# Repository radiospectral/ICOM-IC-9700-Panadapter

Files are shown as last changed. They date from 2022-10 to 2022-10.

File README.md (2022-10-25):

# ICOM-IC-9700-Panadapter
RF out for ICOM-IC-9700

DISCLAIMER:
We are not responsible for any damage to your radio, and this is at your own risk operation.
If you don't have the basic electronic knowledge, we do not suggest you attempt to build this unit.

SCHEMATICS-ICOM-IC-9700-Panadapter.pdf : Schematic file.

gerber.zip                             : Zip archive, constains gerber files for the PCB manufacturing.
                                         You can use jlcpcb.com to order ready to use PCBs.

pcb-manufacture.png                    : PCB manufacturing settings for jlcpcb.com

BOM-ICOM-IC-9700-Panadapter.pdf        : Bill of materials.

fixture-9700.step                      : Fixture step file.  You may also print the part with 3D printer.

IMPORTANT:
The thickness of the PCB should be 1mm, and FR4 should be used as a material.

We encourage you to share this project with other ham radio operators to help them monitor the spectrum of amateur bands
with their SDR receivers. 

We hope our contribution helps the ham radio community to build low cost and effective pan adapters for their rigs.

www.radiospectral.com

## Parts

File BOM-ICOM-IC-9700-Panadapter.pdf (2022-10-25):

Designator | Value | Description | Digi-Key_Purchase_URL | Digi-Key_Part_Number | Quantity
12RIF, 12RIFIN, RF_OUT, URRF, URRFIN, VRRF, VRRFIN | UF.L | Conn Coaxial PL 50Ohm Solder ST SMD Gold Over Nickel | https://www.digikey.com/product-detail/en/te-connectivity-amp-connectors/1909763-1/A118077DKR-ND/4914093 | A118077DKR-ND | 7
C1, C4 | 10uF | Cap Ceramic 10uF 25V X5R 10% SMD 0805 85Â°C Embossed T/R | https://www.digikey.com.tr/product-detail/en/samsung-electro-mechanics/CL21A106KAYNNNE/1276-2891-1-ND/3890977 | 1276-2891-6-ND | 2
C2, C5 | 1uF 16V | Eia Case Size: 0805, Voltage: 50, Cap Value: 1000000, Tol: +/-10%, Thickness: 1.25 Â± 0.20 | https://www.digikey.com/product-detail/en/kemet/C0805C105Z4VACTU/399-8011-6-ND/3472542 | 399-8011-6-ND | 2
C3, C6, C7, C8, C9, CF, CFA, CFB, CFC | 100nF 50V | CAP CER 1000PF 50V C0G/NP0 0805, CAP CER 100nF 50V C0G/NP0 0805, Eia Case Size: 0805, Voltage: 50, Cap Value: 100000, Tol: +/-10%, Thickness: 1.25 Â± 0.20 | https://www.digikey.com/product-detail/en/tdk-corporation/CGA4J2X8R1H104K125AA/445-5909-6-ND/2444516 | 445-5909-6-ND | 9
CINA, CINB, CINC | 100nF | Eia Case Size: 0805, Voltage: 50, Cap Value: 100000, Tol: +/-10%, Thickness: 1.25 Â± 0.20 | https://www.digikey.com/product-detail/en/samsung-electro-mechanics/CL10B104KA8NNNC/1276-1006-1-ND/3889092 | 1276-1006-1-ND | 3
COUT | 10nF | Eia Case Size: 0805, Voltage: 50, Cap Value: 10000, Tol: +/-10%, Thickness: 1.25 Â± 0.20 | https://www.digikey.com/product-detail/en/samsung-electro-mechanics/CL21C103JBF1PNE/1276-6790-6-ND/5962024 | 1276-6790-6-ND | 1
D1 | 1N4148WTR | Diode Standard 75V 250mA (DC) Surface Mount SOD-123 | https://www.digikey.com/product-detail/en/smc-diode-solutions/1N4148WTR/1655-1360-6-ND/6023160 | 1655-1360-6-ND | 1
FL | EMIF-500MHz | LC (Pi) EMI Filter 3rd Order Low Pass 1 Channel L = 31nH | https://www.digikey.com/product-detail/en/murata-electronics/NFL21SP507X1C3D/490-6960-6-ND/3847173 | 490-6960-1-ND | 1
Fsupp | | Thermal Fuse 200mA | https://www.digikey.com/product-detail/en/bel-fuse-inc/0ZCM0020FF2G/507-1821-1-ND/4156270 | 507-1821-1-ND | 1
JPBPIN_0 | 5 Pin | Connector Header Through Hole, Right Angle 5 position 0 | https://www.digikey.com/product-detail/en/jst-sales-america-inc/B5B-PH-K-S-LF-SN/455-1707-ND/926614https://www.digikey.com/en/products/detail/jst-sales-america-inc/P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 | 455-1707-ND | 1
JPBPOUT_0 | 5 Pin | Connector Header Through Hole, Right Angle 5 position 0 | https://www.digikey.com/product-detail/en/jst-sales-america-inc/B5B-PH-K-S-LF-SN/455-1707-ND/926614https://www.digikey.com/en/products/detail/jst-sales-america-inc/P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 | 455-1163-ND | 1
JPOUT_0 | 2 pin | Connector Header Through Hole 2 position 0.079 _2.00mm | https://www.digikey.com/short/z2v159 | 455-1704-ND | 1
LID1 | | Lid for rf-cage. | https://www.digikey.com/product-detail/en/te-connectivity-amp-connectors/2118731-2/A126136-ND/7381875 | A126136-ND | 1
LIN, Lout | 1uH | 1ÂµH Shielded Multilayer Inductor 1.15A 60mOhm 0805 _2012 Metric_ | https://www.digikey.com/product-detail/en/tdk-corporation/MLZ2012N1R0LT000/445-6756-6-ND/2523662 | 445-6756-6-ND | 2
POWER_IN | 2 pin | Connector Header Through Hole, Right Angle 2 position | https://www.digikey.com/product-detail/en/jst-sales-america-inc/S2B-PH-K-S_LF__SN_/455-1719-ND/926626 | 455-1719-ND | 1
POWER_LED | Green LED | LED GREEN DIFFUSED 0805 SMD | https://www.digikey.com/en/products/detail/osram-opto-semiconductors-inc/LG-R971-KN-1/1227925 | 475-1410-6-ND | 1
R10, R20, R30, R40, R50, R60 | 20k | Res Thick Film 0805 20K Ohm 1% 0.125W_1/8W_ ?100pp | https://www.digikey.com/en/products/detail/yageo/RT0603FRE0720KL/1075194 | YAG5727DKR-ND | 6
RF1 | 150R | 150 Ohms Â±1% 0.125W, 1/8W Chip Resistor 0805 (2012 Met (https://www.digikey.com/product-detail/en/yageo/RC0805FR-07150RL/311-150CRDKR-ND/733507) | https://www.digikey.com/product-detail/en/yageo/RC0805FR-07150RL/311-150CRDKR-ND/733507 | 311-150CRDKR-ND | 1
RF2, RFA2, RFB2, RFC2 | 270R | 270 Ohms Â±1% 0.125W, 1/8W Chip Resistor 0805 (2012 Met (https://www.digikey.com/product-detail/en/te-connectivity-passive-product/CRGCQ0805F270R/A129742DKR-ND/8578804) | https://www.digikey.com/product-detail/en/te-connectivity-passive-product/CRGCQ0805F270R/A129742DKR-ND/8578804 | A129742DKR-ND | 4
RFA1 | 100R | 100 Ohms Â±1% 0.125W, 1/8W Chip Resistor 0805 (2012 Met (https://www.digikey.com/product-detail/en/yageo/RC0805FR-07100RL/311-100CRDKR-ND/733437) | https://www.digikey.com/product-detail/en/yageo/RC0805FR-07100RL/311-100CRDKR-ND/733437 | 311-100CRDKR-ND | 1
RFB1 | 82R | 82 Ohms Â±1% 0.125W, 1/8W Chip Resistor 0805 (2012 Metr (https://www.digikey.com/product-detail/en/yageo/RC0805FR-0782RL/311-82-0CRDKR-ND/734058) | https://www.digikey.com/product-detail/en/yageo/RC0805FR-0782RL/311-82-0CRDKR-ND/734058 | 311-82.0CRDKR-ND | 1
RFC1 | 220R | 220 Ohms Â±1% 0.125W, 1/8W Chip Resistor 0805 (2012 Met (https://www.digikey.com/short/znc2q9) | https://www.digikey.com/short/znc2q9 | A129741DKR-ND | 1
RFSHIELD | | Rf cage. | https://www.digikey.com/product-detail/en/te-connectivity-amp-connectors/2118732-2/A126160CT-ND/7381920 | A126160TR-ND | 1
RG | 1k | 0805/Case Surface Mount/Pkg 1/10-Watt 1k-Ohms 1pct-Tol | https://www.digikey.com.tr/product-detail/en/yageo/RC0805FR-071KL/311-1.00KCRCT-ND/730391 | 311-1.00KCRDKR-ND | 1
RLA, RLB, RLC | 100R | 0805/Case Surface Mount/Pkg 1/10-Watt 1k-Ohms 1pct-Tol | https://www.digikey.com/short/znc2b8 | 311-100CRDKR-ND | 3
RLED | 10k | 2.2 kOhms Â±1% 0.125W, 1/8W Chip Resistor 0805 _2012 Metric_ Moisture Resistant Thick Film | https://www.digikey.com/short/znc28v | 311-10.0KCRDKR-ND | 1
RS | 49R9 | 49.9 Ohms Â±1% 0.125W, 1/8W Chip Resistor 0805 (2012 Me (https://www.digikey.com/product-detail/en/yageo/RC0805FR-0749R9L/311-49-9CRDKR-ND/733878) | https://www.digikey.com/product-detail/en/yageo/RC0805FR-0749R9L/311-49-9CRDKR-ND/733878 | 311-49.9CRDKR-ND | 1
U1 | LM7810 | Linear Voltage Regulator IC 1 Output 1A SOT-223-4 | https://www.digikey.com/product-detail/en/texas-instruments/LM2940IMP-10-NOPB/LM2940IMP-10-NOPBDKR-ND/1847195 | LM2940IMP-10/NOPBDKR-ND | 1
U2, U3, U4, U5 | LMH6702 | Current Feedback OpAmp | https://www.digikey.com/product-detail/en/texas-instruments/LMH6702MF-NOPB/LMH6702MF-NOPBDKR-ND/1847728 | LMH6702MF/NOPBDKR-ND | 4
cable1 | ipex-ipex cable | u.fl female to u.fl female cable 10 cm | https://www.digikey.com/en/products/detail/te-connectivity-amp-connectors/2118651-6/11205742 | 17-2118651-6-ND | 3
cable2 | ipex-sma | sma female to u.fl female cable 30 cm | https://www.digikey.com/en/products/detail/adam-tech/CA-DKCA0-305L0-AJI0-O/9831216 | 2057-CA-DKCA0-305L0-AJI0-O-ND | 1

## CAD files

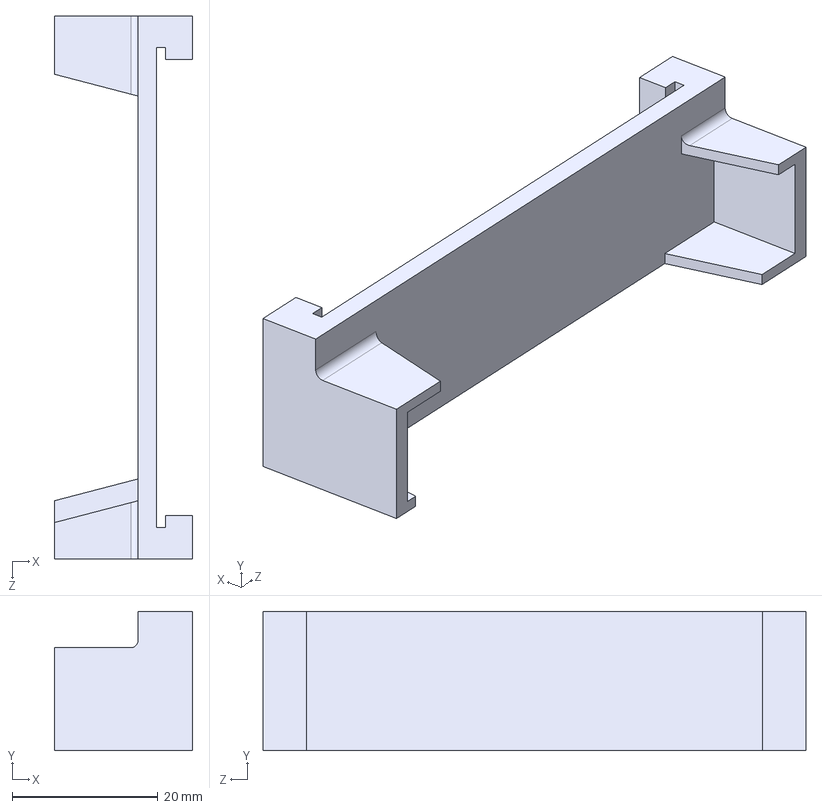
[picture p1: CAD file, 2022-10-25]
fixture-9700.step
19.0 x 19.1 x 74.6 mm

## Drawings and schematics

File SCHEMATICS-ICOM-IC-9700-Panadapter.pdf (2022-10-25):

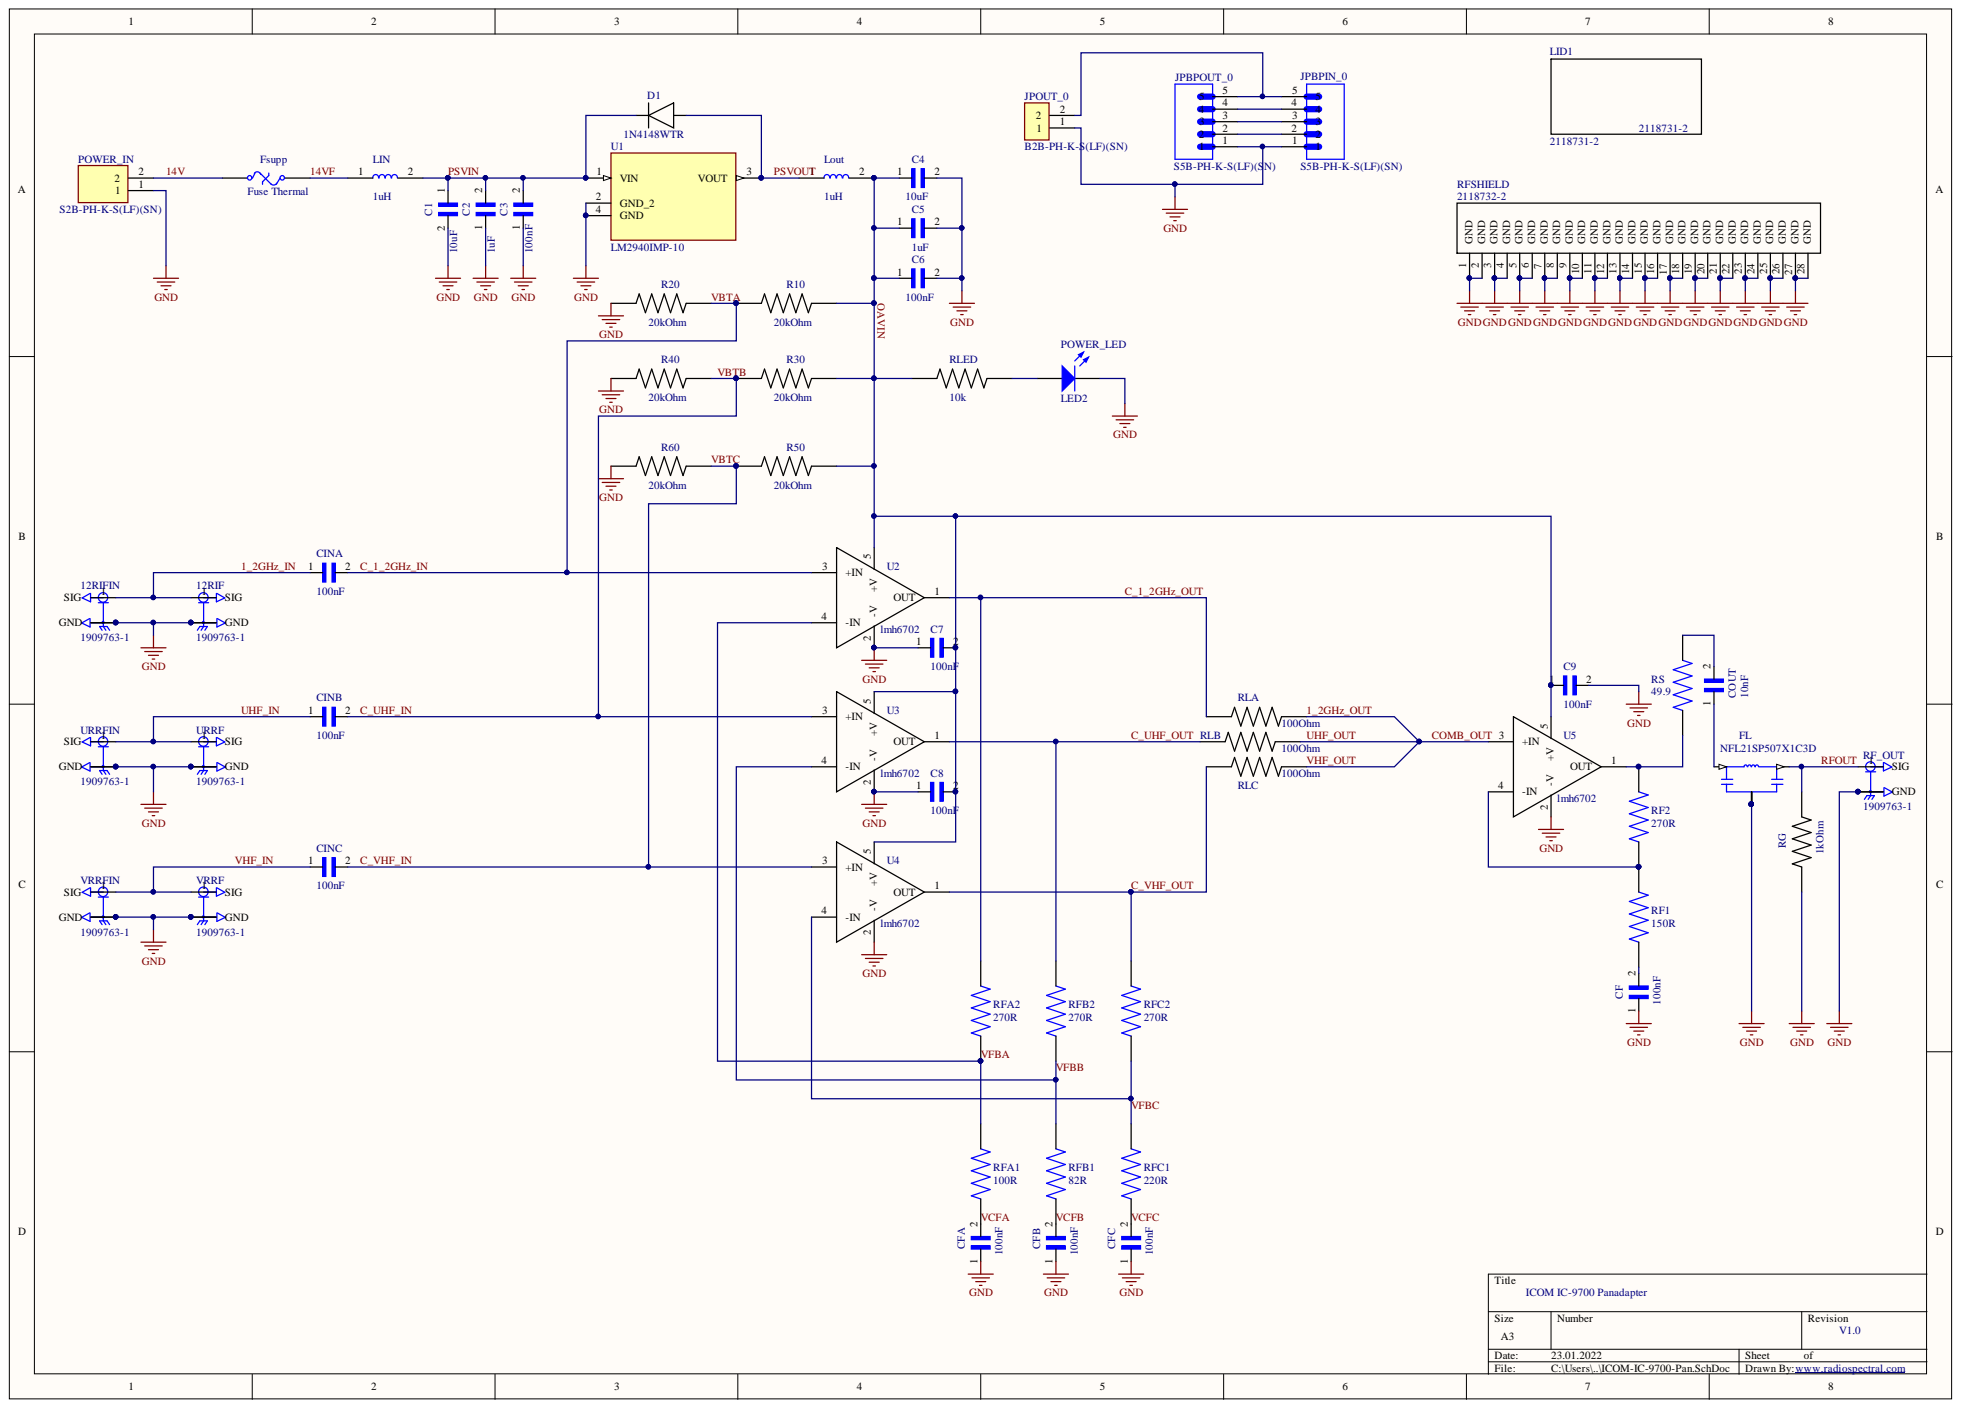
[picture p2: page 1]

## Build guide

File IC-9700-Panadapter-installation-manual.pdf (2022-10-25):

### www.radiospectral.com

ICOM IC-9700 Panadapter INSTALLATION GUIDE

DISCLAIMER: We are not responsible for any damage to your radio during installation. Please operate at your own risk.

This document has been prepared to guide you to install ICOM IC-9700 Panadapter into your ICOM IC-9700 radio. This is solderless operation, and you can remove ICOM IC-9700 Panadapter from your radio at any time easily without any modification.

ICOM IC-9700 Panadapter shipped with following items as shown in Figure.1:

1- ICOM IC-9700 Panadapter.
2- Fixture (non-conductive). 3- U.FL extensions.
4- Power cable.
5- Power adapter.
6- U.FL to SMA cable and SMA fixture.

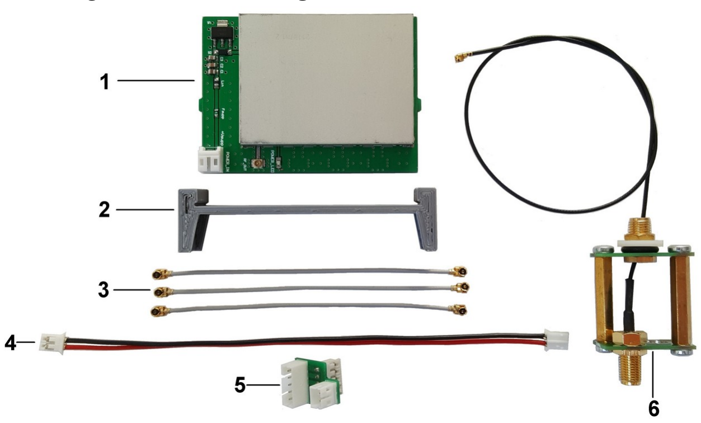
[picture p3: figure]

Figure.1 : ICOM IC-9700 Panadapter product content. Installation Procedure
Before you start, you will need an 8mm wrench to replace the SMA connector and also a phillips head screwdriver to remove the bottom cover of IC-9700.

1- Power off your IC-9700 and remove power cable.
2- Open the bottom cover of IC-9700 with a phillips head screwdriver.
3- Plug the power adapter as in Figure.2.
4- Detach U.FL cables from the PCB of IC-9700 then attach U.FL cables extensions to IC-9700 (VHFin, UHFin, 23in) as shown in Figure.3. Do not forget to attach original U.FL cables from IC-9700 to ICOM IC-9700 Panadapter.
5- Replace REF_IN SMA connector with supplied adapter as shown in Figure.4 (if you don’t use REF_IN signal, you can replace the SMA connector with supplied one) as in Figure.5.
6- Push ICOM IC-9700 Panadapter on to the aluminum holder as in Figure.3, then attach the power cable to ICOM IC-9700 Panadapter.
7- Power your IC-9700 on and check if the green LED of ICOM IC-9700 Panadapter is on as in Figure.6.
8- Close the bottom cover. Connect your SDR receiver to the RF output of ICOM IC-9700 Panadapter.
9- You are all set. Enjoy your ICOM IC-9700 Panadapter !

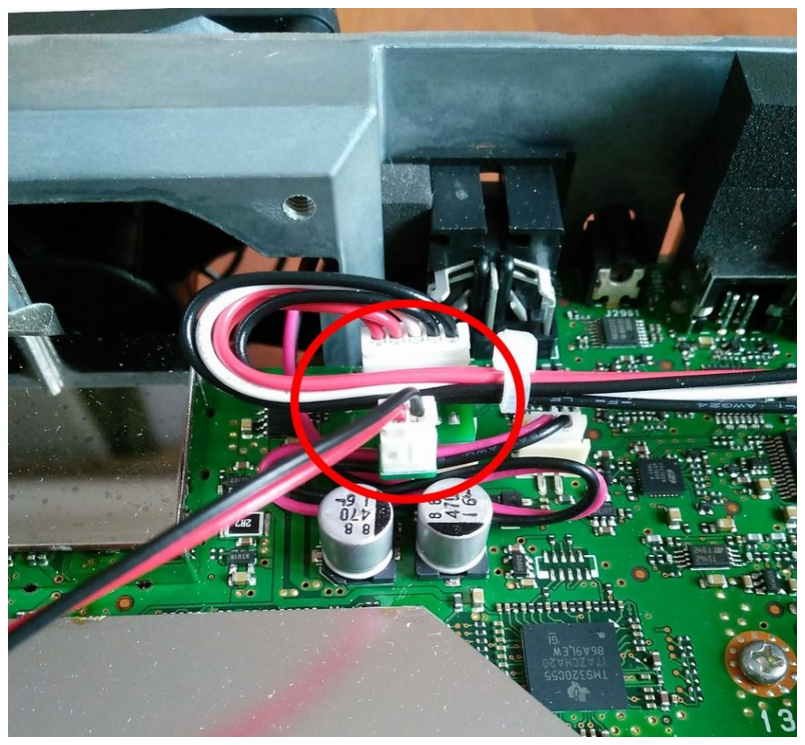
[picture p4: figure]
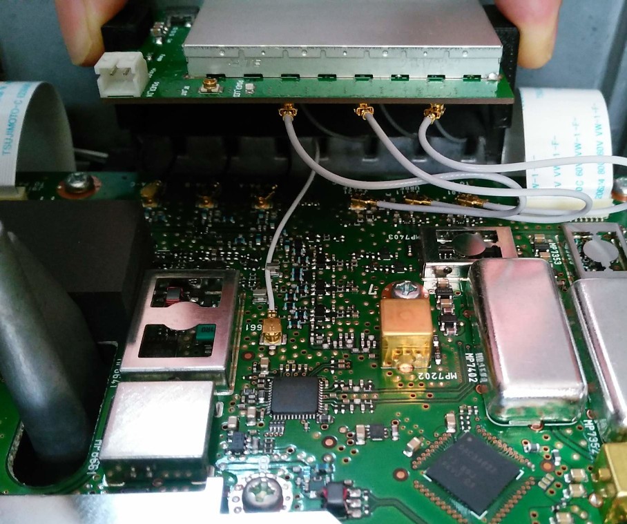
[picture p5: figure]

Figure.2 : Power adapter connection. | Figure.3 : Bypass cable connections.

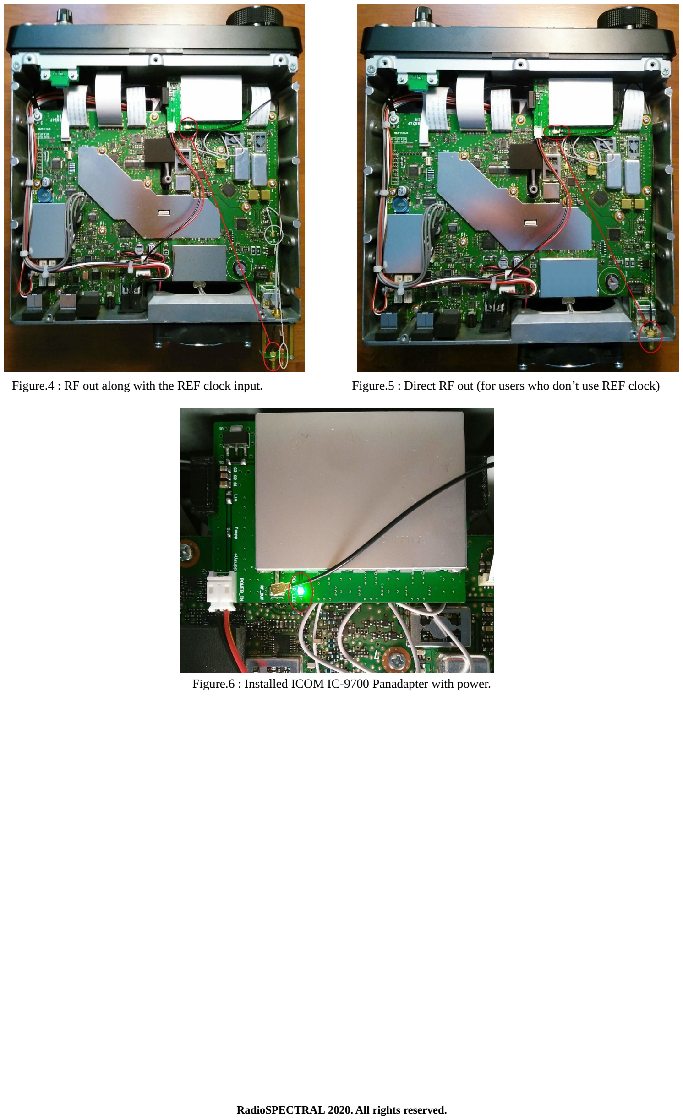
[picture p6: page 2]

Figure.4 : RF out along with the REF clock input. | Figure.5 : Direct RF out (for users who don’t use REF clock)

Figure.6 : Installed ICOM IC-9700 Panadapter with power.

RadioSPECTRAL 2020. All rights reserved.

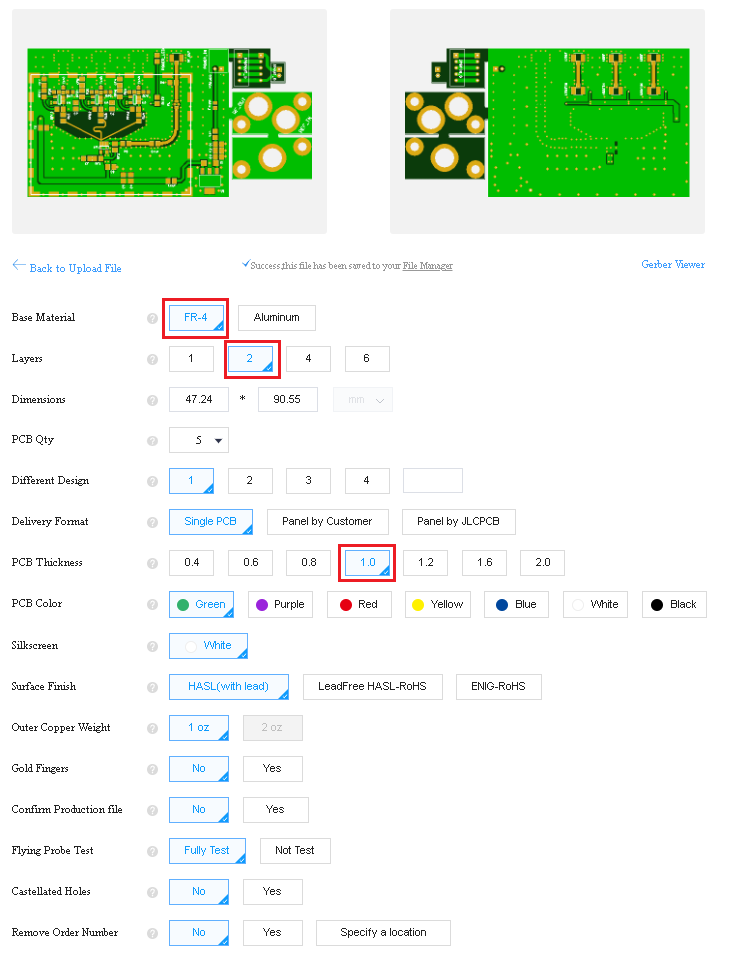
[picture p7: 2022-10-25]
pcb-manufacture.png
